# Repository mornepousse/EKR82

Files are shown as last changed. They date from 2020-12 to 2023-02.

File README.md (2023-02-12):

# EKR82 Keyboard

Work in Progress...

EN:

I took the Lily58 and added my personal touch by including a column and row layout for ease of use. I added function keys on top for more efficient use of special functions and an extra macro column for even further customization to my liking. And to top it all off, I added a thumb button for easy access to an important function. In short, the EKR82 is a custom keyboard that I created to meet all of my needs

FR:

J'ai pris le Lily58 et j'ai ajouté ma touche personnelle en y incluant une disposition en colonnes et en rangées pour une utilisation facile. J'ai ajouté des touches de fonction en haut pour une utilisation plus efficace des fonctions spéciales et une colonne de macros pour une personnalisation encore plus poussée a mon goût. Et pour couronner le tout, j'ai ajouté une touche pour le pouce pour un accès facile à une fonction importante. Bref, le EKR82 est un clavier sur mesure que j'ai créé pour répondre à tous mes besoins.

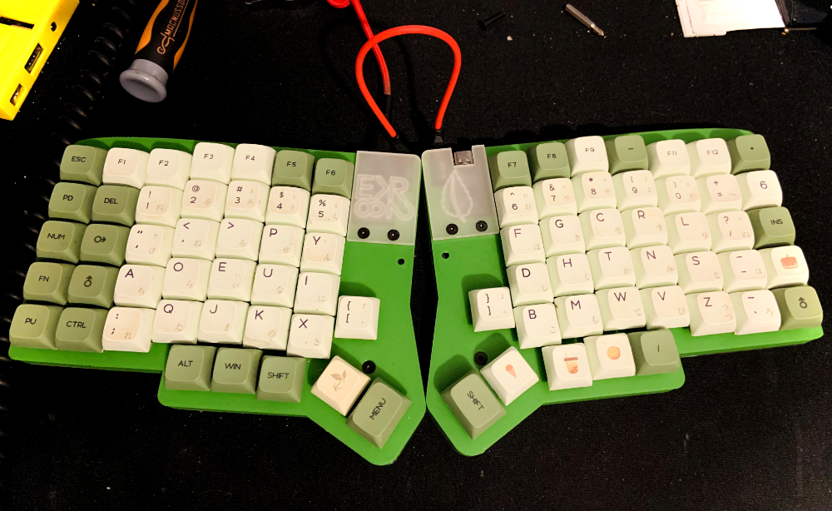
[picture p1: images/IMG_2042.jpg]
EKR82


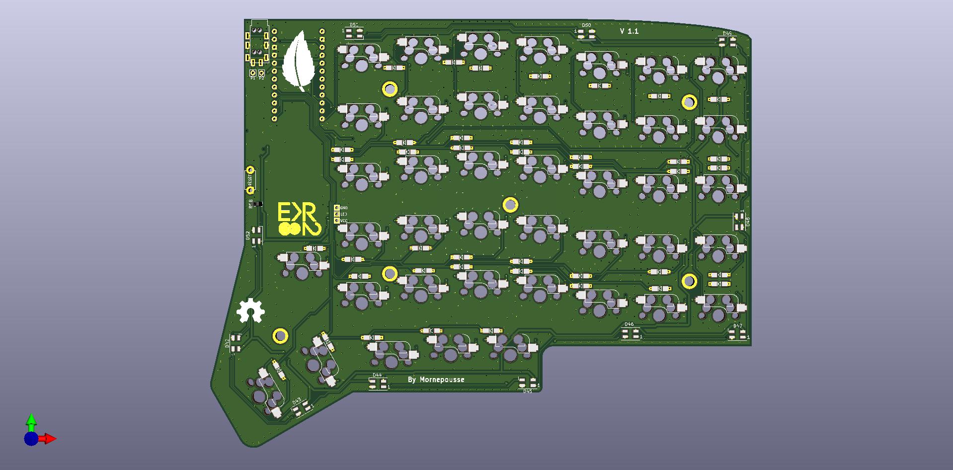
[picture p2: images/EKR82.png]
EKR82image


lily58 forki

by mornepousse

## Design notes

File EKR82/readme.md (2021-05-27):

# EKR82

EKR82 is 7×5+6keys column-staggered split keyboard.

schematic:
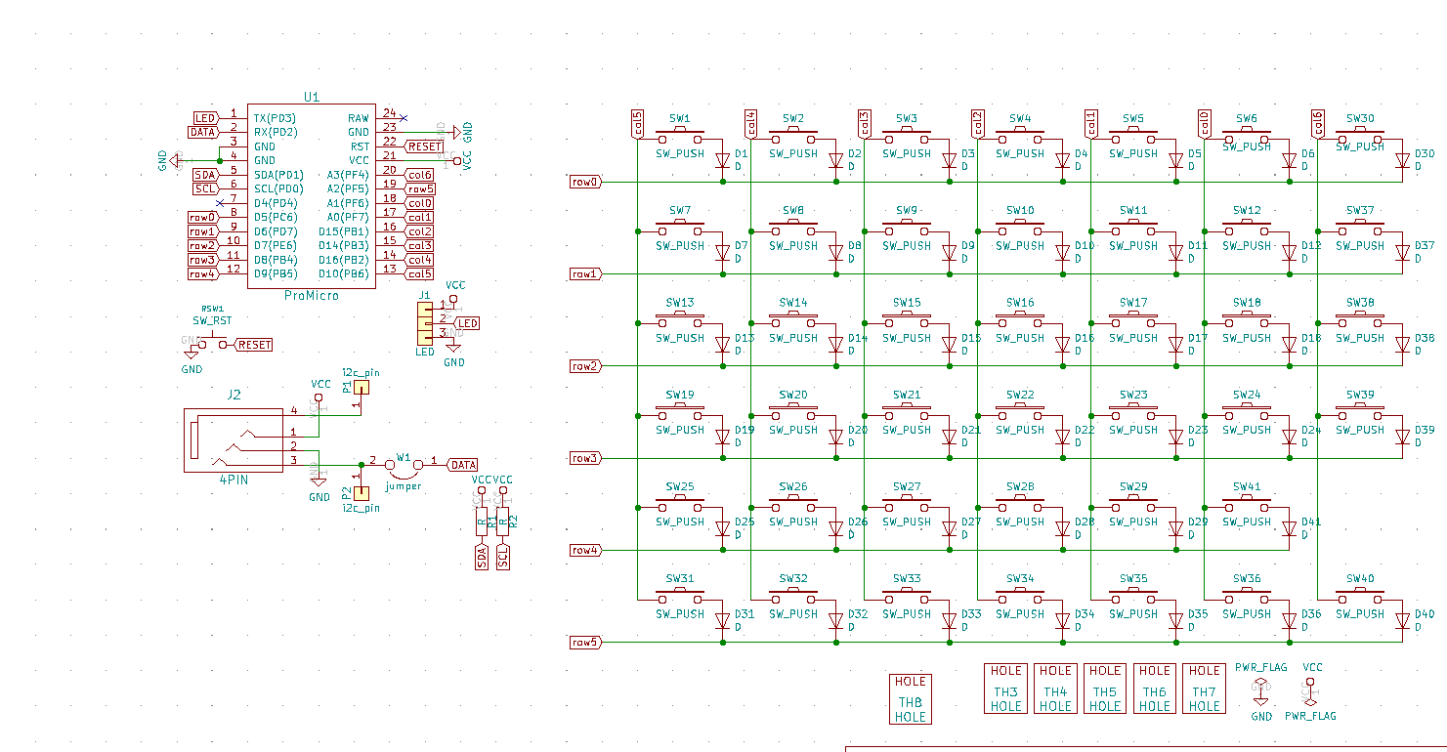
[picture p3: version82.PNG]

Hardware Supported: EKR82 PCB, ProMicro, goldfish 

Make example for this keyboard (after setting up your build environment):

    make EKR82:via

See the [build environment setup](https://docs.qmk.fm/#/getting_started_build_tools) and the [make instructions](https://docs.qmk.fm/#/getting_started_make_guide) for more information. Brand new to QMK? Start with our [Complete Newbs Guide](https://docs.qmk.fm/#/newbs).

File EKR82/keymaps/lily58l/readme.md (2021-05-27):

# EKR82L


A modified EKR82 pcb, with underglow, per key rgb light and rotary encoder support.
- SK6812 Mini-E per key led's (58x) for easy soldering
- 6x SK6812 Mini led's per side for underglow
- Support for 1 rotary encoder on each side

Left encoder: volume up/down, next/previous track on RAISE layer  
Right encoder: cursor down/up, right/left on LOWER layer

* Keyboard Maintainer: BenRoe [GitHub](https://github.com/BenRoe) / [Twitter](https://twitter.com/keycapsss)
* Hardware Supported: Pro Micro, or Elite-C
* Hardware Availability: [Keycapsss.com](https://keycapsss.com)

Make example for this keyboard (after setting up your build environment):
 
    make EKR82/light:EKR82l

Flashing example for this keyboard:

    make EKR82/light:EKR82l:flash
    
See the [build environment setup](https://docs.qmk.fm/#/getting_started_build_tools) and the [make instructions](https://docs.qmk.fm/#/getting_started_make_guide) for more information. Brand new to QMK? Start with our [Complete Newbs Guide](https://docs.qmk.fm/#/newbs).

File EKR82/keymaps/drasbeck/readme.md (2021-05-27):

## Danish (Dansk) layout for the EKR82 Pro
Keyboard: EKR82 Pro  
Keys: EKR82 Pro is 6×4+5keys column-staggered split keyboard, optinal with a rotary encoder.  
Flash instructions: Flash each side of the keyboard, minding whether the side uses a Pro Micro or Elite-C controller.  

### Layout
Danish special characters on main layer, moving other characters to mainly raised layer.

Layer 0 = default  
Layer 1 = lower  
Layer 2 = raise  

keymap

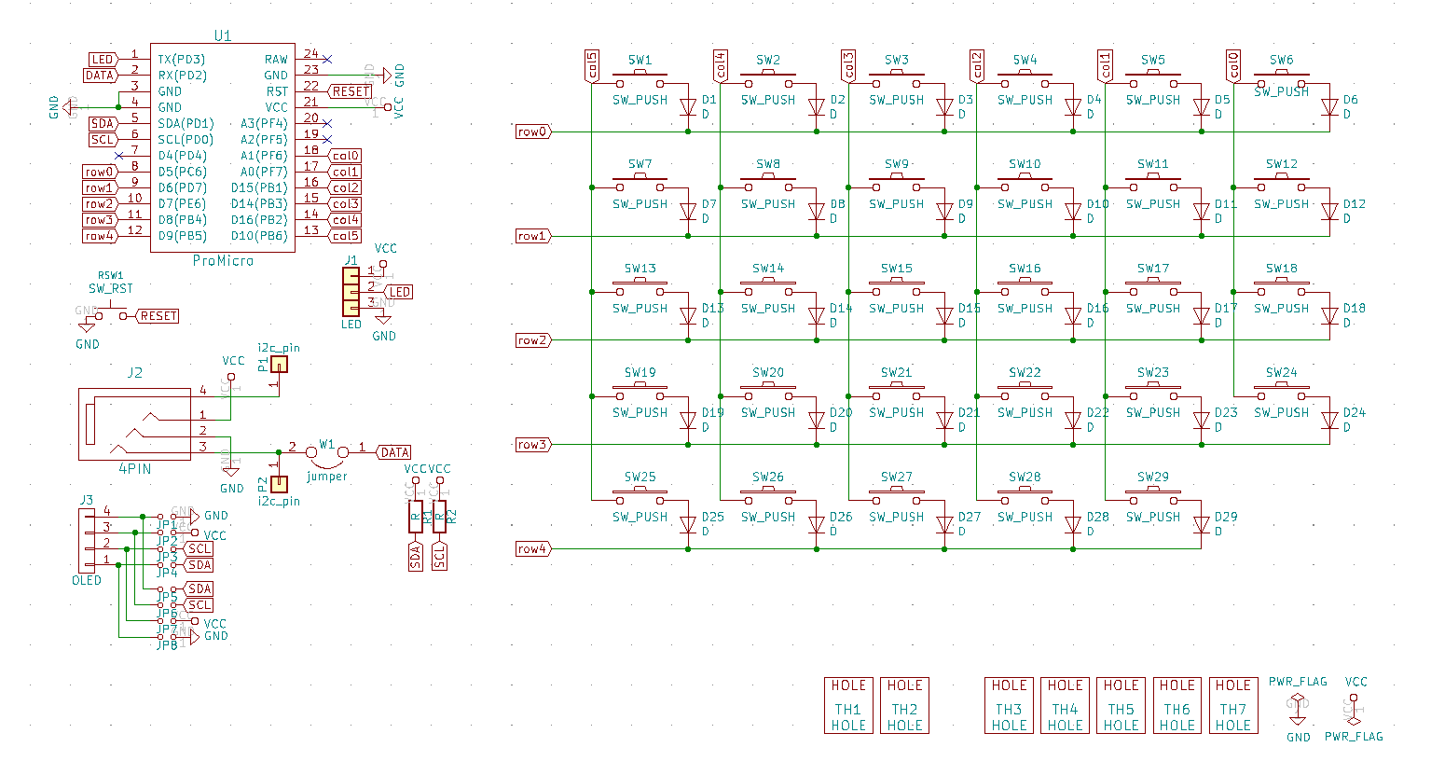
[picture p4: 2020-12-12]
version58.PNG

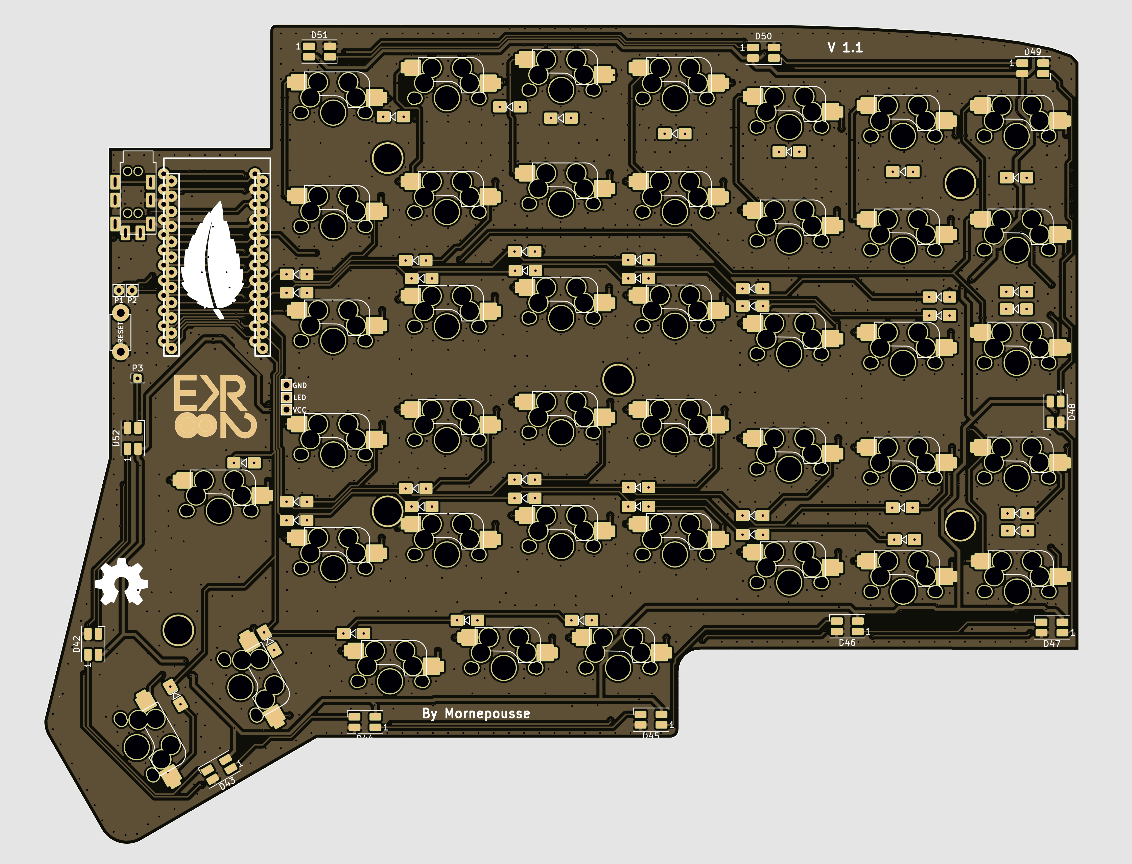
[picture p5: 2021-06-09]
images/jlc.PNG

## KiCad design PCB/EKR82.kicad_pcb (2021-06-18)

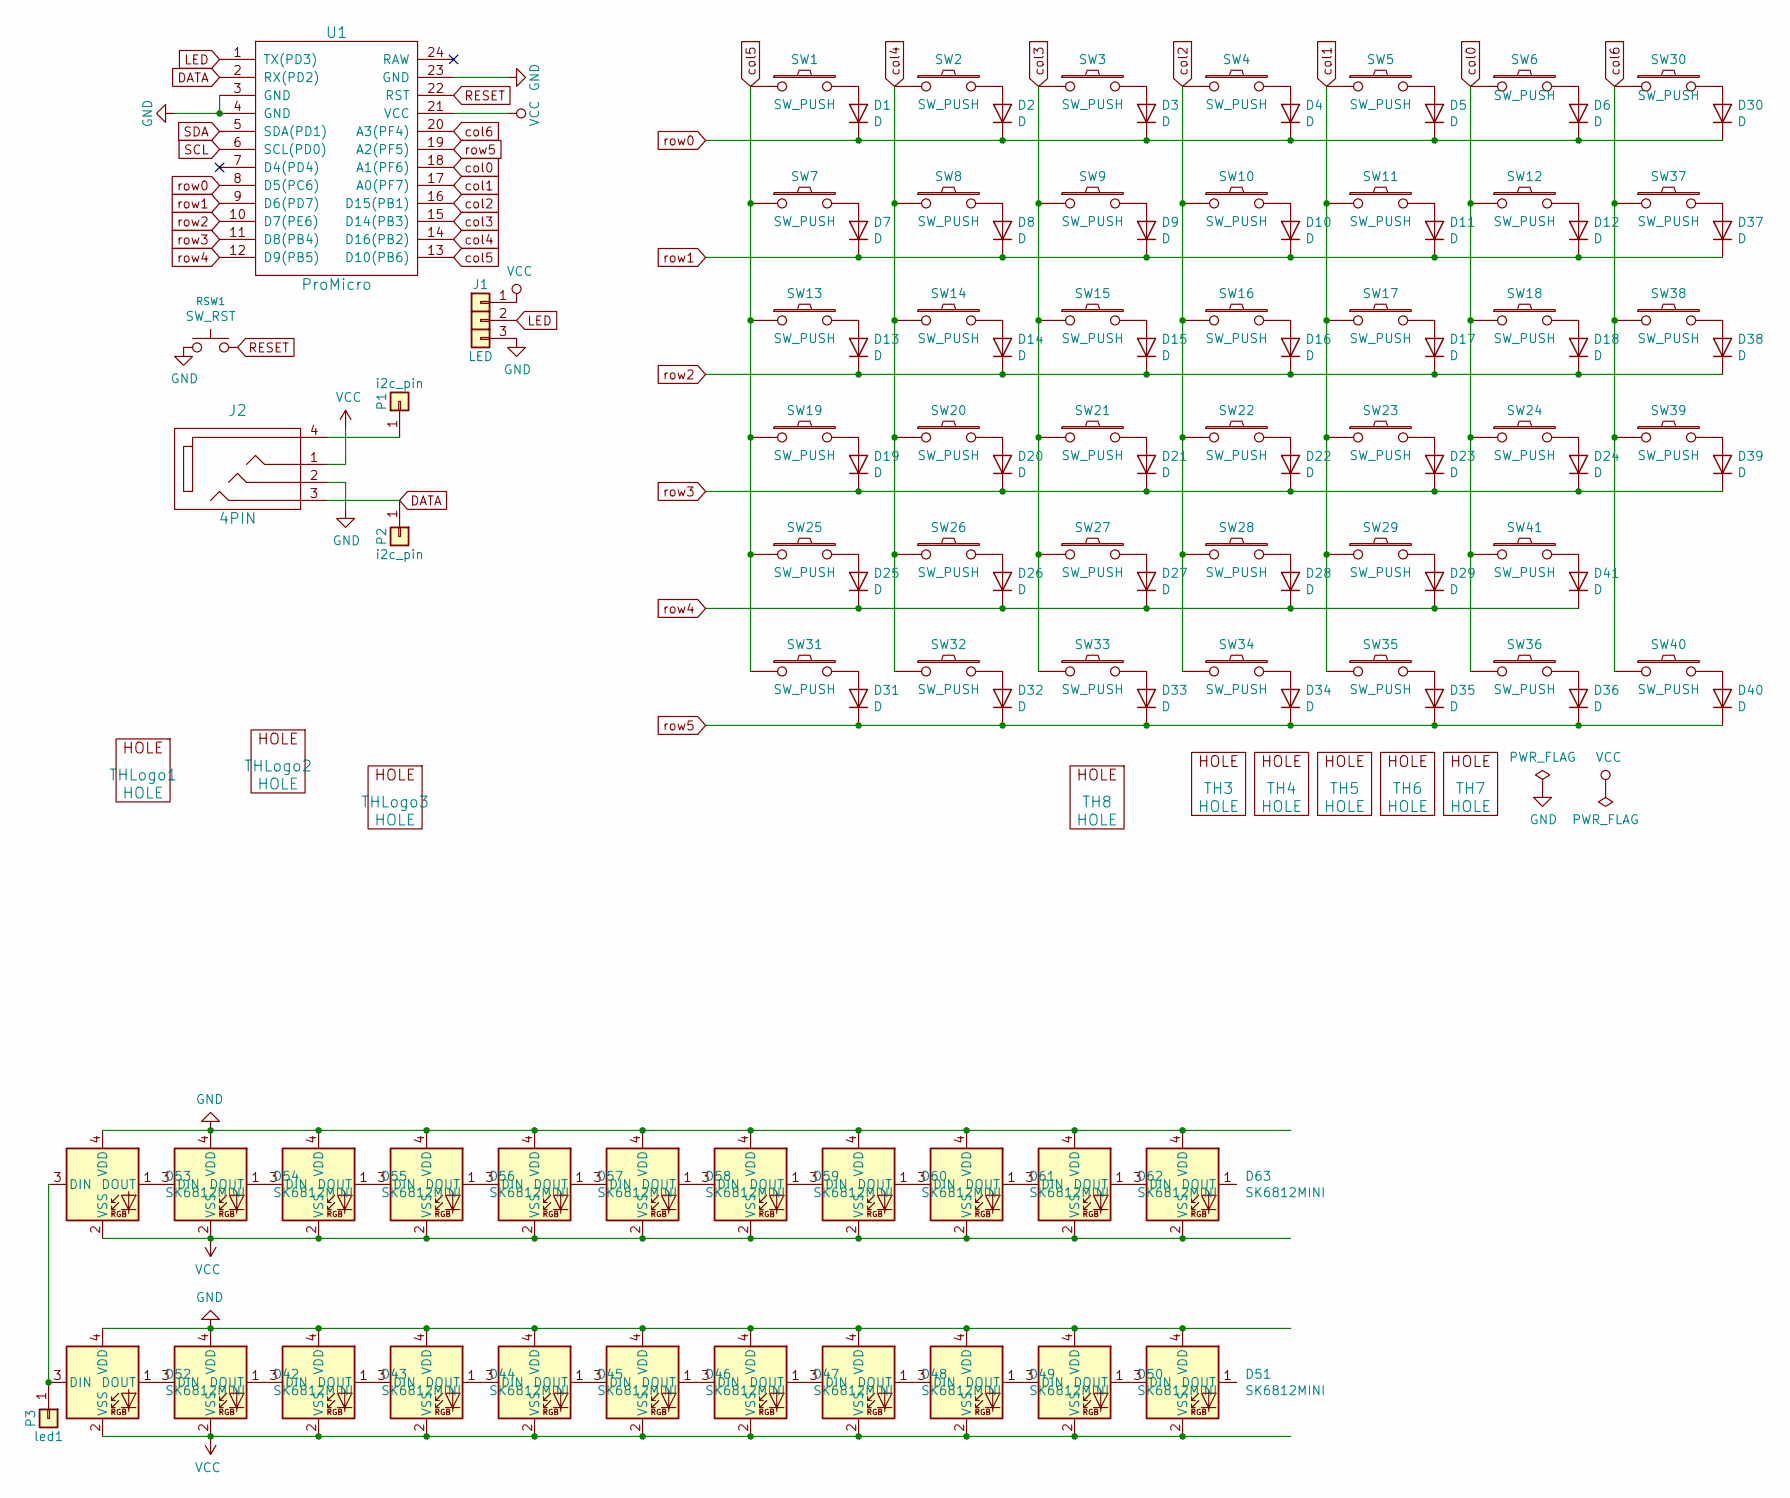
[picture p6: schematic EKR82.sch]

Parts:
D1, D2, D3, D4, D5, D6, D7, D8, D9, D10, D11, D12, D13, D14, D15, D16, D17, D18, D19, D20, D21, D22, D23, D24, D25, D26, D27, D28, D29, D30, D31, D32, D33, D34, D35, D36, D37, D38, D39, D40, D41: D; Diode_SOD123
D42, D43, D44, D45, D46, D47, D48, D49, D50, D51, D52, D53, D54, D55, D56, D57, D58, D59, D60, D61, D62, D63: SK6812MINI; LED_SK6812MINI_PLCC4_3.5x3.5mm_P1.75mm
J1: LED
J2: 4PIN; MJ-4PP-9
P1, P2: i2c_pin; 1pin_conn
P3: led1; PinHeader_1x01_P1.27mm_Vertical
RSW1: SW_RST; TACT_SWITCH_TVBP06
SW1, SW2, SW3, SW4, SW5, SW6, SW7, SW8, SW9, SW10, SW11, SW12, SW13, SW14, SW15, SW16, SW17, SW18, SW19, SW20, SW21, SW22, SW23, SW24, SW25, SW26, SW27, SW28, SW29, SW30, SW31, SW32, SW33, SW34, SW35, SW36, SW37, SW38, SW39, SW40, SW41: SW_PUSH; CherryMX_KailhLowProfile_Hotswap_edge-2
TH3, TH4, TH5, TH6, TH7, TH8: HOLE; HOLE_M2_TH
THLogo1: HOLE; EKR82-2
THLogo2, THLogo3: HOLE; OSHW-Symbol_8.9x8mm_SilkScreen
U1: ProMicro; ProMicro_rev

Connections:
DATA: J2.3, P2.1, U1.2 (RX(PD2))
GND: D42.4 (VDD), D43.4 (VDD), D44.4 (VDD), D45.4 (VDD), D46.4 (VDD), D47.4 (VDD), D48.4 (VDD), D49.4 (VDD), D50.4 (VDD), D51.4 (VDD), D52.4 (VDD), D53.4 (VDD), D54.4 (VDD), D55.4 (VDD), D56.4 (VDD), D57.4 (VDD), D58.4 (VDD), D59.4 (VDD), D60.4 (VDD), D61.4 (VDD), D62.4 (VDD), D63.4 (VDD), J1.3, J2.2, RSW1.1, U1.3 (GND), U1.4 (GND), U1.23 (GND)
LED: J1.2, U1.1 (TX(PD3))
unnamed: D1.2 (A), SW1.2
unnamed: D2.2 (A), SW2.2
unnamed: D3.2 (A), SW3.2
unnamed: D4.2 (A), SW4.2
unnamed: D5.2 (A), SW5.2
unnamed: D6.2 (A), SW6.2
unnamed: D7.2 (A), SW7.2
unnamed: D8.2 (A), SW8.2
unnamed: D9.2 (A), SW9.2
unnamed: D10.2 (A), SW10.2
unnamed: D11.2 (A), SW11.2
unnamed: D12.2 (A), SW12.2
unnamed: D13.2 (A), SW13.2
unnamed: D14.2 (A), SW14.2
unnamed: D15.2 (A), SW15.2
unnamed: D16.2 (A), SW16.2
unnamed: D17.2 (A), SW17.2
unnamed: D18.2 (A), SW18.2
unnamed: D19.2 (A), SW19.2
unnamed: D20.2 (A), SW20.2
unnamed: D21.2 (A), SW21.2
unnamed: D22.2 (A), SW22.2
unnamed: D23.2 (A), SW23.2
unnamed: D24.2 (A), SW24.2
unnamed: D25.2 (A), SW25.2
unnamed: D26.2 (A), SW26.2
unnamed: D27.2 (A), SW27.2
unnamed: D28.2 (A), SW28.2
unnamed: D29.2 (A), SW29.2
unnamed: D30.2 (A), SW30.2
unnamed: D31.2 (A), SW31.2
unnamed: D32.2 (A), SW32.2
unnamed: D33.2 (A), SW33.2
unnamed: D34.2 (A), SW34.2
unnamed: D35.2 (A), SW35.2
unnamed: D36.2 (A), SW36.2
unnamed: D37.2 (A), SW37.2
unnamed: D38.2 (A), SW38.2
unnamed: D39.2 (A), SW39.2
unnamed: D40.2 (A), SW40.2
unnamed: D41.2 (A), SW41.2
unnamed: D42.1 (DOUT), D43.3 (DIN)
unnamed: D42.3 (DIN), D52.1 (DOUT)
unnamed: D43.1 (DOUT), D44.3 (DIN)
unnamed: D44.1 (DOUT), D45.3 (DIN)
unnamed: D45.1 (DOUT), D46.3 (DIN)
unnamed: D46.1 (DOUT), D47.3 (DIN)
unnamed: D47.1 (DOUT), D48.3 (DIN)
unnamed: D48.1 (DOUT), D49.3 (DIN)
unnamed: D49.1 (DOUT), D50.3 (DIN)
unnamed: D50.1 (DOUT), D51.3 (DIN)
unnamed 55: D52.3 (DIN), D53.3 (DIN), P3.1; also elsewhere on the board
unnamed: D53.1 (DOUT), D54.3 (DIN)
unnamed: D54.1 (DOUT), D55.3 (DIN)
unnamed: D55.1 (DOUT), D56.3 (DIN)
unnamed: D56.1 (DOUT), D57.3 (DIN)
unnamed: D57.1 (DOUT), D58.3 (DIN)
unnamed: D58.1 (DOUT), D59.3 (DIN)
unnamed: D59.1 (DOUT), D60.3 (DIN)
unnamed: D60.1 (DOUT), D61.3 (DIN)
unnamed: D61.1 (DOUT), D62.3 (DIN)
unnamed: D62.1 (DOUT), D63.3 (DIN)
unnamed: J2.4, P1.1
RESET: RSW1.2, U1.22 (RST)
SCL: U1.6 (SCL(PD0))
SDA: U1.5 (SDA(PD1))
VCC: D42.2 (VSS), D43.2 (VSS), D44.2 (VSS), D45.2 (VSS), D46.2 (VSS), D47.2 (VSS), D48.2 (VSS), D49.2 (VSS), D50.2 (VSS), D51.2 (VSS), D52.2 (VSS), D53.2 (VSS), D54.2 (VSS), D55.2 (VSS), D56.2 (VSS), D57.2 (VSS), D58.2 (VSS), D59.2 (VSS), D60.2 (VSS), D61.2 (VSS), D62.2 (VSS), D63.2 (VSS), J1.1, J2.1, U1.21 (VCC)
col0: SW6.1, SW12.1, SW18.1, SW24.1, SW36.1, SW41.1, U1.18 (A1(PF6))
col1: SW5.1, SW11.1, SW17.1, SW23.1, SW29.1, SW35.1, U1.17 (A0(PF7))
col2: SW4.1, SW10.1, SW16.1, SW22.1, SW28.1, SW34.1, U1.16 (D15(PB1))
col3: SW3.1, SW9.1, SW15.1, SW21.1, SW27.1, SW33.1, U1.15 (D14(PB3))
col4: SW2.1, SW8.1, SW14.1, SW20.1, SW26.1, SW32.1, U1.14 (D16(PB2))
col5: SW1.1, SW7.1, SW13.1, SW19.1, SW25.1, SW31.1, U1.13 (D10(PB6))
col6: SW30.1, SW37.1, SW38.1, SW39.1, SW40.1, U1.20 (A3(PF4))
row0: D1.1 (K), D2.1 (K), D3.1 (K), D4.1 (K), D5.1 (K), D6.1 (K), D30.1 (K), U1.8 (D5(PC6))
row1: D7.1 (K), D8.1 (K), D9.1 (K), D10.1 (K), D11.1 (K), D12.1 (K), D37.1 (K), U1.9 (D6(PD7))
row2: D13.1 (K), D14.1 (K), D15.1 (K), D16.1 (K), D17.1 (K), D18.1 (K), D38.1 (K), U1.10 (D7(PE6))
row3: D19.1 (K), D20.1 (K), D21.1 (K), D22.1 (K), D23.1 (K), D24.1 (K), D39.1 (K), U1.11 (D8(PB4))
row4: D25.1 (K), D26.1 (K), D27.1 (K), D28.1 (K), D29.1 (K), D41.1 (K), U1.12 (D9(PB5))
row5: D31.1 (K), D32.1 (K), D33.1 (K), D34.1 (K), D35.1 (K), D36.1 (K), D40.1 (K), U1.19 (A2(PF5))

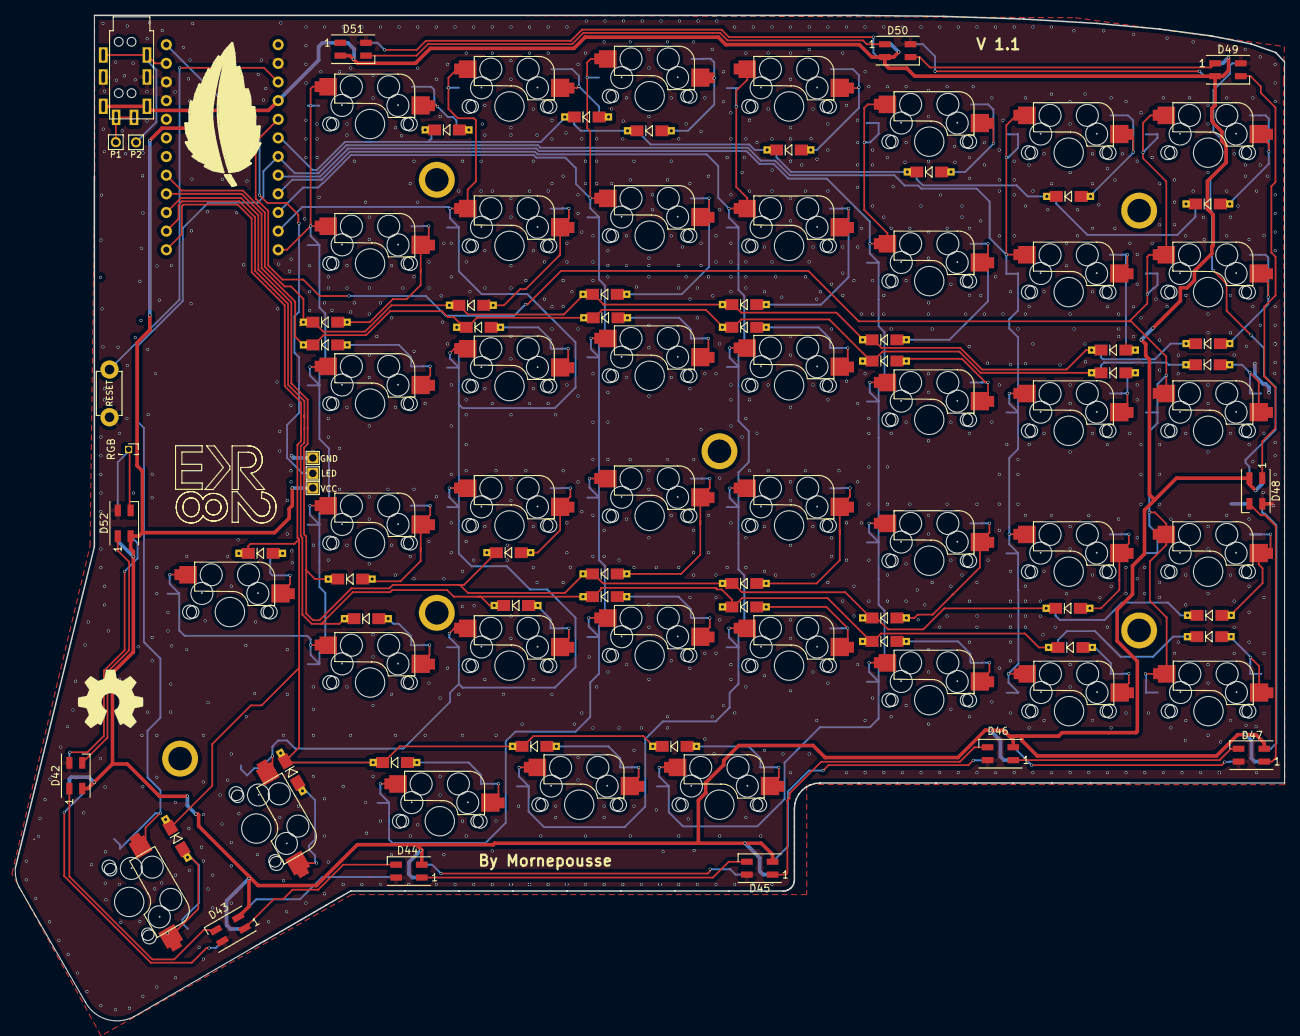
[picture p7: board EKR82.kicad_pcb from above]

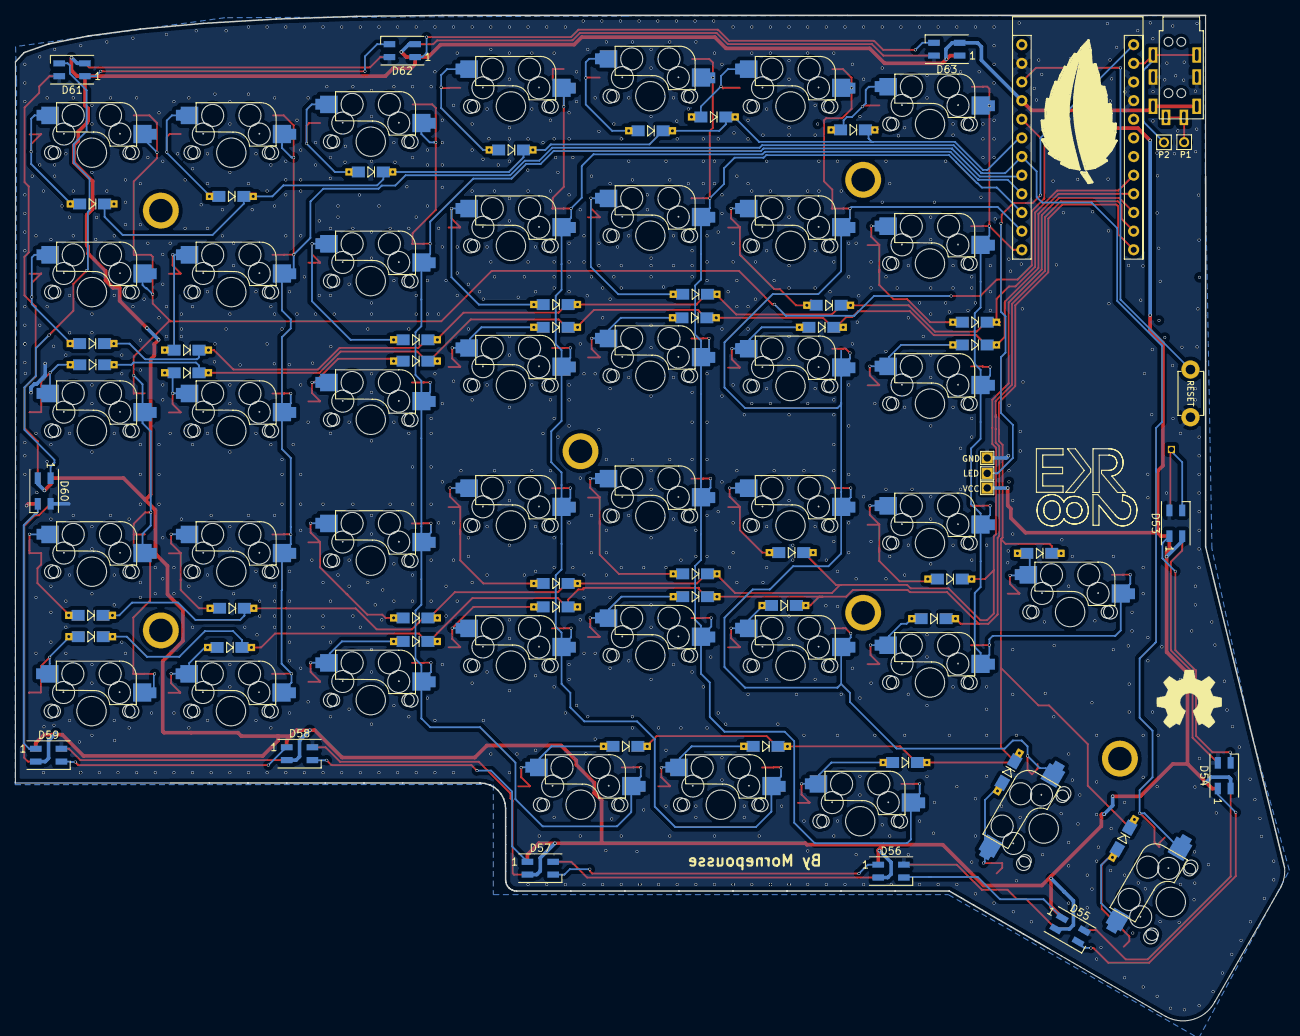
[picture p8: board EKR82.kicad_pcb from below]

Board: 2 copper layers, 173.0 x 137.0 mm, 121 parts (13 on the bottom side), 81 nets.

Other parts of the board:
RGB: led1; PinSocket_1x01_P1.27mm_Vertical
THLogo1#2: HOLE; EKR82-2

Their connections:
unnamed 55: RGB.1; also elsewhere on the board

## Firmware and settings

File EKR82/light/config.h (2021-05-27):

/*
Copyright 2012 Jun Wako <wakojun@gmail.com>
Copyright 2015 Jack Humbert
Copyright 2017 F_YUUCHI
Copyright 2020 Ben Roesner (keycapsss.com)

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
You should have received a copy of the GNU General Public License
along with this program.  If not, see <http://www.gnu.org/licenses/>.
*/

#pragma once

/* USB Device descriptor parameter */
#define VENDOR_ID       0x7983
#define PRODUCT_ID      0x4C4C // "LL"
#define DEVICE_VER      0x0100
#define MANUFACTURER    Keycapsss
#define PRODUCT         EKR82L

/* key matrix size */
// Rows are doubled-up
#define MATRIX_ROWS 10
#define MATRIX_COLS 6

// wiring of each half
#define MATRIX_ROW_PINS { C6, D7, E6, B4, B5 }
#define MATRIX_COL_PINS { F6, F7, B1, B3, B2, B6 }

/* Set 0 if debouncing isn't needed */
#define DEBOUNCE 5

#define SOFT_SERIAL_PIN D2

#define RGB_DI_PIN D3
#define RGBLED_SPLIT { 35, 35 }
#define RGBLED_NUM 70
#define RGBLIGHT_SPLIT
#define RGBLIGHT_LIMIT_VAL 120

#define ENCODERS_PAD_A { F4 }
#define ENCODERS_PAD_B { F5 }
#define ENCODERS_PAD_A_RIGHT { F5 }
#define ENCODERS_PAD_B_RIGHT { F4 }

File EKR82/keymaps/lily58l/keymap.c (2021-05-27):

 /* Copyright 2017 F_YUUCHI
  * Copyright 2020 Drashna Jaelre <@drashna>
  * Copyright 2020 Ben Roesner (keycapsss.com)
  *
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
  * You should have received a copy of the GNU General Public License
  * along with this program.  If not, see <http://www.gnu.org/licenses/>.
  */

#include QMK_KEYBOARD_H


extern uint8_t is_master;

enum layers {
    _QWERTY,
    _LOWER,
    _RAISE,
    _ADJUST,
};

#define RAISE MO(_RAISE)
#define LOWER MO(_LOWER)

const uint16_t PROGMEM keymaps[][MATRIX_ROWS][MATRIX_COLS] = {

/* QWERTY
 * ,-----------------------------------------.                    ,-----------------------------------------.
 * | ESC  |   1  |   2  |   3  |   4  |   5  |                    |   6  |   7  |   8  |   9  |   0  |  `   |
 * |------+------+------+------+------+------|                    |------+------+------+------+------+------|
 * | Tab  |   Q  |   W  |   E  |   R  |   T  |                    |   Y  |   U  |   I  |   O  |   P  |  -   |
 * |------+------+------+------+------+------|                    |------+------+------+------+------+------|
 * |LCTRL |   A  |   S  |   D  |   F  |   G  |-------.    ,-------|   H  |   J  |   K  |   L  |   ;  |  '   |
 * |------+------+------+------+------+------|   [   |    |    ]  |------+------+------+------+------+------|
 * |LShift|   Z  |   X  |   C  |   V  |   B  |-------|    |-------|   N  |   M  |   ,  |   .  |   /  |RShift|
 * `-----------------------------------------/       /     \      \-----------------------------------------'
 *                   | LAlt | LGUI |LOWER | /Space  /       \Enter \  |RAISE |BackSP| RGUI |
 *                   |      |      |      |/       /         \      \ |      |      |      |
 *                   `----------------------------'           '------''--------------------'
 */

 [_QWERTY] = LAYOUT(
  KC_ESC,   KC_1,   KC_2,    KC_3,    KC_4,    KC_5,                     KC_6,    KC_7,    KC_8,    KC_9,    KC_0,    KC_GRV,
  KC_TAB,   KC_Q,   KC_W,    KC_E,    KC_R,    KC_T,                     KC_Y,    KC_U,    KC_I,    KC_O,    KC_P,    KC_MINS,
  KC_LCTRL, KC_A,   KC_S,    KC_D,    KC_F,    KC_G,                     KC_H,    KC_J,    KC_K,    KC_L,    KC_SCLN, KC_QUOT,
  KC_LSFT,  KC_Z,   KC_X,    KC_C,    KC_V,    KC_B, KC_LBRC,  KC_RBRC,  KC_N,    KC_M,    KC_COMM, KC_DOT,  KC_SLSH,  KC_RSFT,
                             KC_LALT, KC_LGUI,LOWER, KC_SPC,   KC_ENT,   RAISE,   KC_BSPC, KC_RGUI
),
/* LOWER
 * ,-----------------------------------------.                    ,-----------------------------------------.
 * |      |      |      |      |      |      |                    |      |      |      |      |      |      |
 * |------+------+------+------+------+------|                    |------+------+------+------+------+------|
 * |  F1  |  F2  |  F3  |  F4  |  F5  |  F6  |                    |  F7  |  F8  |  F9  | F10  | F11  | F12  |
 * |------+------+------+------+------+------|                    |------+------+------+------+------+------|
 * |   `  |   !  |   @  |   #  |   $  |   %  |-------.    ,-------|   ^  |   &  |   *  |   (  |   )  |   -  |
 * |------+------+------+------+------+------|   [   |    |    ]  |------+------+------+------+------+------|
 * |      |      |      |      |      |      |-------|    |-------|      |   _  |   +  |   {  |   }  |   |  |
 * `-----------------------------------------/       /     \      \-----------------------------------------'
 *                   | LAlt | LGUI |LOWER | /Space  /       \Enter \  |RAISE |BackSP| RGUI |
 *                   |      |      |      |/       /         \      \ |      |      |      |
 *                   `----------------------------'           '------''--------------------'
 */
[_LOWER] = LAYOUT(
  _______, _______, _______, _______, _______, _______,                   _______, _______, _______,_______, _______, _______,
  KC_F1,   KC_F2,   KC_F3,   KC_F4,   KC_F5,   KC_F6,                     KC_F7,   KC_F8,   KC_F9,   KC_F10,  KC_F11,  KC_F12,
  KC_GRV, KC_EXLM, KC_AT,   KC_HASH, KC_DLR,  KC_PERC,                   KC_CIRC, KC_AMPR, KC_ASTR, KC_LPRN, KC_RPRN, KC_TILD,
  _______, _______, _______, _______, _______, _______, _______, _______, XXXXXXX, KC_UNDS, KC_PLUS, KC_LCBR, KC_RCBR, KC_PIPE,
                             _______, _______, _______, _______, _______,  _______, _______, _______
),
/* RAISE
 * ,-----------------------------------------.                    ,-----------------------------------------.
 * |      |      |      |      |      |      |                    |      |      |      |      |      |      |
 * |------+------+------+------+------+------|                    |------+------+------+------+------+------|
 * |   `  |   1  |   2  |   3  |   4  |   5  |                    |   6  |   7  |   8  |   9  |   0  |      |
 * |------+------+------+------+------+------|                    |------+------+------+------+------+------|
 * |  F1  |  F2  |  F3  |  F4  |  F5  |  F6  |-------.    ,-------|      | Left | Down |  Up  |Right |      |
 * |------+------+------+------+------+------|   [   |    |    ]  |------+------+------+------+------+------|
 * |  F7  |  F8  |  F9  | F10  | F11  | F12  |-------|    |-------|   +  |   -  |   =  |   [  |   ]  |   \  |
 * `-----------------------------------------/       /     \      \-----------------------------------------'
 *                   | LAlt | LGUI |LOWER | /Space  /       \Enter \  |RAISE |BackSP| RGUI |
 *                   |      |      |      |/       /         \      \ |      |      |      |
 *                   `----------------------------'           '------''--------------------'
 */
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

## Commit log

2021-05-26 update kicad project
    [Lily58_Pro-B_Cu.gbl, Lily58_Pro-B_Fab.gbr, Lily58_Pro-B_Mask.gbs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]
2021-05-26 change name lily58 to EKR82
    [EKR82_Pro.kicad_pcb, EKR82_Pro.sch]
2021-05-26 rename kicad project EKR82_Pro to EKR82
    [EKR82.kicad_pcb, EKR82.sch]
2021-06-08 move SW41 and remove resistors
    [EKR82.kicad_pcb, EKR82.sch]
2021-06-09 add backlight rgb WIP
    [EKR82.kicad_pcb, EKR82.sch]
2021-06-09 add led and logo
    [EKR82-B_Cu.gbl, EKR82-B_Fab.gbr, EKR82-B_Mask.gbs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]
2021-06-09 add image jlc
    [EKR82-B_Cu.gbl, EKR82-B_Fab.gbr, EKR82-B_Mask.gbs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]
2021-06-16 Add top PCB and change diode footprint
    [EKR82-B_Cu.gbl, EKR82-B_Fab.gbr, EKR82-B_Mask.gbs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]
2021-06-17 change arduino footprint and move
    [EKR82.kicad_pcb, EKR82.sch]
2021-06-18 little ajustements
    [EKR82-B_Cu.gbl, EKR82-B_Fab.gbr, EKR82-B_Mask.gbs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]
2021-07-15 Add PCB 3D image

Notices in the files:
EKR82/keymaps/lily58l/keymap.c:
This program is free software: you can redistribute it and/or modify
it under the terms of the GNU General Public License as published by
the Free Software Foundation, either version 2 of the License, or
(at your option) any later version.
